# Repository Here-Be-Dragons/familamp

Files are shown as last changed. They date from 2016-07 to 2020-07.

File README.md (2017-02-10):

# familamp

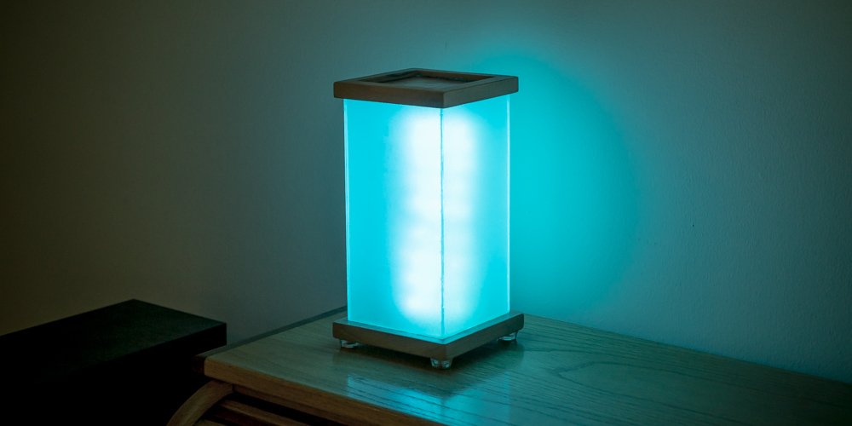
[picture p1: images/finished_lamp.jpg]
Finished Lamp Example


### Overview
---------------------
Networked lamps using a Particle Photon, WB2812B LEDs (aka NeoPixels), and a touch-sensitive panel.  They communicate and synchronize colors across lamps via the internet and Particle's cloud using Particle.subscribe() and Particle.publish() functions.  Bonus of using Particle's cloud: easily push updates and add features from Particle's browser-based IDE and Console.

### Images
---------------------
Demo of operation:  
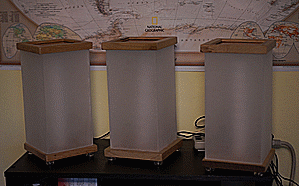
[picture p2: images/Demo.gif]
Demo Operation
  
https://youtu.be/uUX5NEsEXrw
  
Special mode idle sequences (instead of being off, the lamp runs an assigned idle sequence on holidays)
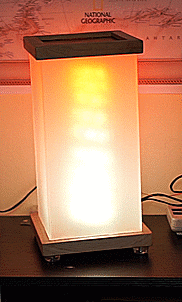
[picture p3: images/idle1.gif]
Christmas Idle

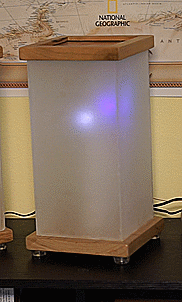
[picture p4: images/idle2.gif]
New Years/4th of July

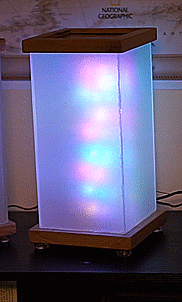
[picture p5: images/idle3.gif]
Birthdays

  
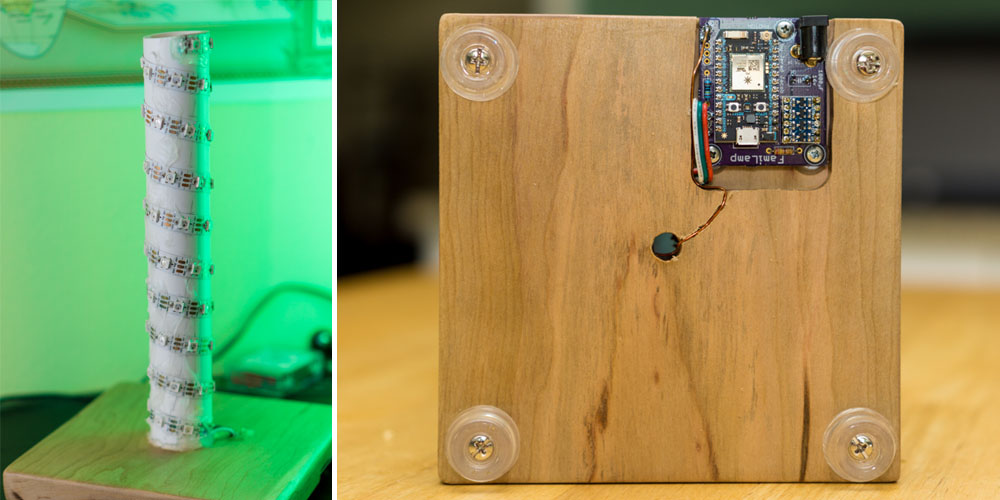
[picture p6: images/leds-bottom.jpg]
Bottom of lamp

  
Circuit boards from Osh Park:
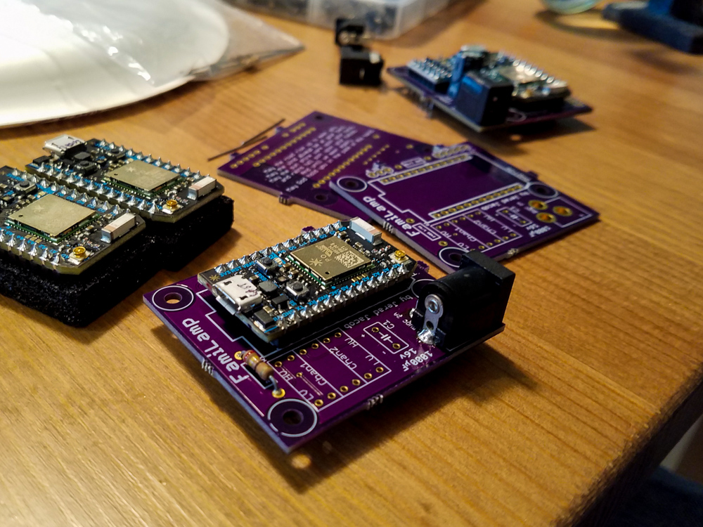
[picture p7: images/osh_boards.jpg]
Osh Park boards


### Hardware
---------------------
-   Particle Photon
-   WB2812B strip of LEDs.  I used 60 per lamp, because this seemed like a good match for my 2A power supplies.
-   A 3.3V to 5V logic level shifter to convert the 3.3V data bus from the Particle Photon to 5V the NeoPixels require.
-   Pre-cut acrylic pieces to make the acrylic light box.  TAP Plastics was the vendor I chose for this. (See *Other Note #1*)  For each lamp:
    -   2 cut-to-size 1/8" thick pieces, 5" x 9-7/8"
	-   2 cut-to-size 1/8" thick pieces, 4-3/4" x 9-7/8"
	-   1 cut-to-size 1/8" thick piece, 5" x 5"
-   A sheet of thin copper for the top.  I used a smooth ball peen hammer on the copper before installation to give it a hammered look.
-   Wood for the base and any flourishes you want for your lamps
-   3/4" x 3/4" outside corner moulding (if desired, to hide seems).
    -   http://www.homedepot.com/p/Alexandria-Moulding-WM-206-3-4-in-x-3-4-in-x-96-in-Wood-Red-Oak-Outside-Corner-Moulding-0W206-40096C/205917014
-   Custom PCB (I designed this in EAGLE and requested manufacture by OSH Park)
-   Other supporting bits (per lamp):
	-   1 resistor of value between 300 and 500 Ohms
	-   1 resistor of value between 1MOhm and 10MOhm (See *Other Note #2*)
	-   A barrel jack of matching dimensions to your power supply (Mine were 5.5mm with a 2.1mm center pole)
	-   A 5V power supply able to power the lamp.  I chose a UL listed supply of 2A. (See *Other Note #3*)
	-   Feet for the bottom of the lamp.  I grabbed some rubber feet from my local hardware supply store.
	-   Mounting hardware to attach the PCB.  I used small screws and standoffs from my local hardware supply store.

### Software
---------------------
-   Particle's Cloud
-   NeoPixel Library: https://github.com/adafruit/Adafruit_NeoPixel (Already ported to Particle's Libraries)
-   CapSense library: https://github.com/lbt/captouch (Already ported to Particle's Libraries)

### Assembly
---------------------
-   1MOhm resistor between pins D3 and D4 of the Particle Photon
-   D2 goes to a 3.3V to 5V Logic Level Shifter, then to a resistor of value between 300 to 500 Ohms, then to the data input pin of the NeoPixels.
    -   The resistor prevents voltage spikes that might otherwise damange the first pixel in the string.
-   D3 of the Particle Photon is connected to the touch sensitive hammered copper panel on the top of the lamp.
-   Connect a capacitor (1000µF, 6.3V or higher) across VIN and GND on the Particle Photon, then connect VIN and GND to the corresponding NeoPixel pins.
    -   The 1000µF capacitor prevents the initial onrush of current from damaging the pixels over time.  I ended up using a 500µF capacitor instead so it would fit my design's physical contraints better.
-   I used a 9" length of 1" PVC pipe to wrap the NeoPixels around, and hot-glued this into a hole in the top of the wood base.
    -   Do not use hot glue to glue the NeoPixels to the PVC pipe.  Either buy the NeoPixels with 3M tape on the back or use something like silicone (do not power the pixels on until after the time indicated for complete dry time on the glue of choice to prevent shorting the pixels).  When I used hot glue, this caused the strip to stop working correctly

### Other Notes & Lessons Learned
---------------------
1.  I tried saving money here by buying a large sheet of clear acrylic and cutting it myself, then sanding to make clear into frosted.  It turns out cutting acrylic is not easy to do well.  Abandoned this idea and bought clear acrylic pre-cut from a vendor, then sanded with 60-grit using a random orbital sander to frost the acrylic.  This still took forever.  If I were to do it again, I'd just buy pre-frosted with a medium light pass-through level.
2.  A lower resistance is less sensitive, but also polls faster. A high resistance takes longer to poll but can detect changes to capacitance with more sensitivity.  Prototype between 1MOhm and 10MOhm to see what works with your design.  I chose 1m ohm because the code loops back through a the captouch poll function frequently in the middle of effect transitions. It does this to try to be responsive to touch as quickly as possible.  In really dry weather it does slow down polling significantly which has the end result of making slightly stuttery animation effects, even with 1MOhm.
3.  Try to avoid power supplies that are not UL-Listed.  2A was a good middle ground for a reliable supply.  This device draws ~1A at 5V on its brightest setting during typical usage.  If all LEDs are at maximum brightness white (not something available in the current code), the lamp draws almost 3A.

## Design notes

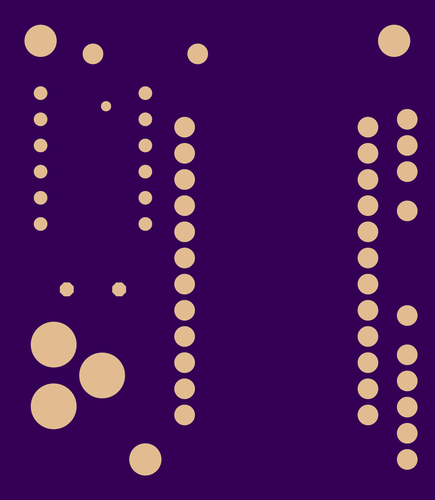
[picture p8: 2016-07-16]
images/OSH Park/ccddc78fc4526e5253ced44dfe0e408c.png

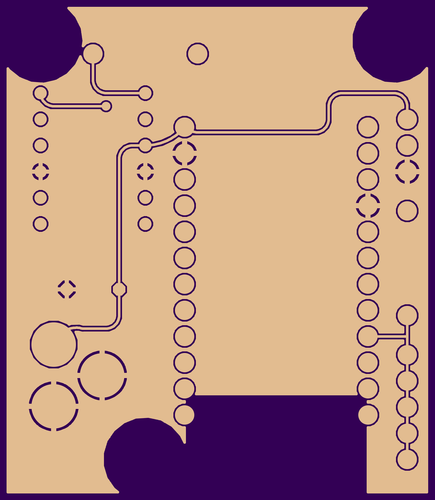
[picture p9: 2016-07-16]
images/OSH Park/2b33153ba39a5f5864be22afad9369f5.png

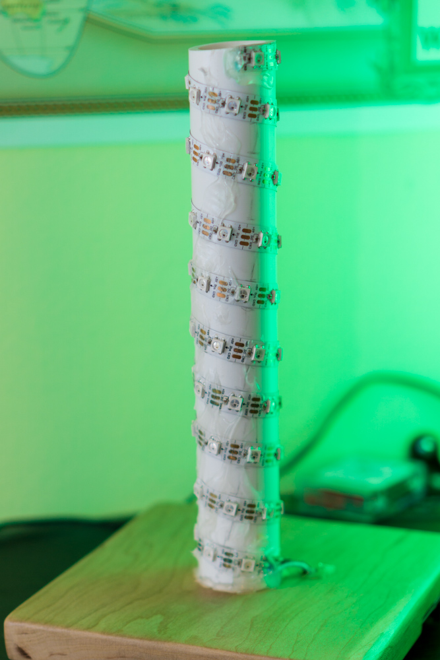
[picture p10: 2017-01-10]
images/leds.jpg

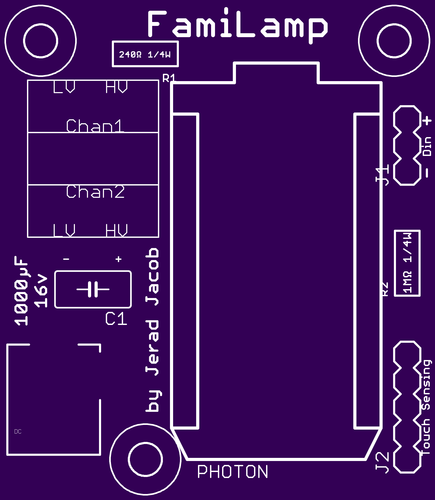
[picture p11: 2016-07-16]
images/OSH Park/a5ede5240e57ebc49895208856950a84.png

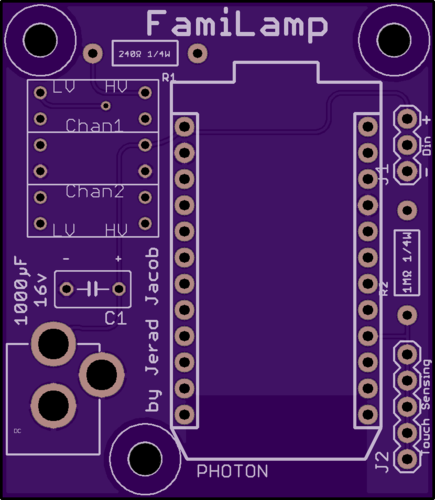
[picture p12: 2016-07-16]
images/OSH Park/2d7f82fe96bacb948cefc18041535cae.png

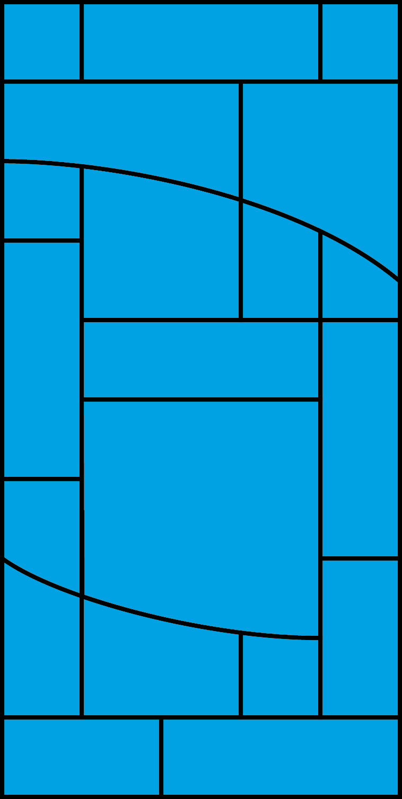
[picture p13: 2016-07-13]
images/SketchUp/familamp.png

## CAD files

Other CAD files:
images/SketchUp/familamp.skp

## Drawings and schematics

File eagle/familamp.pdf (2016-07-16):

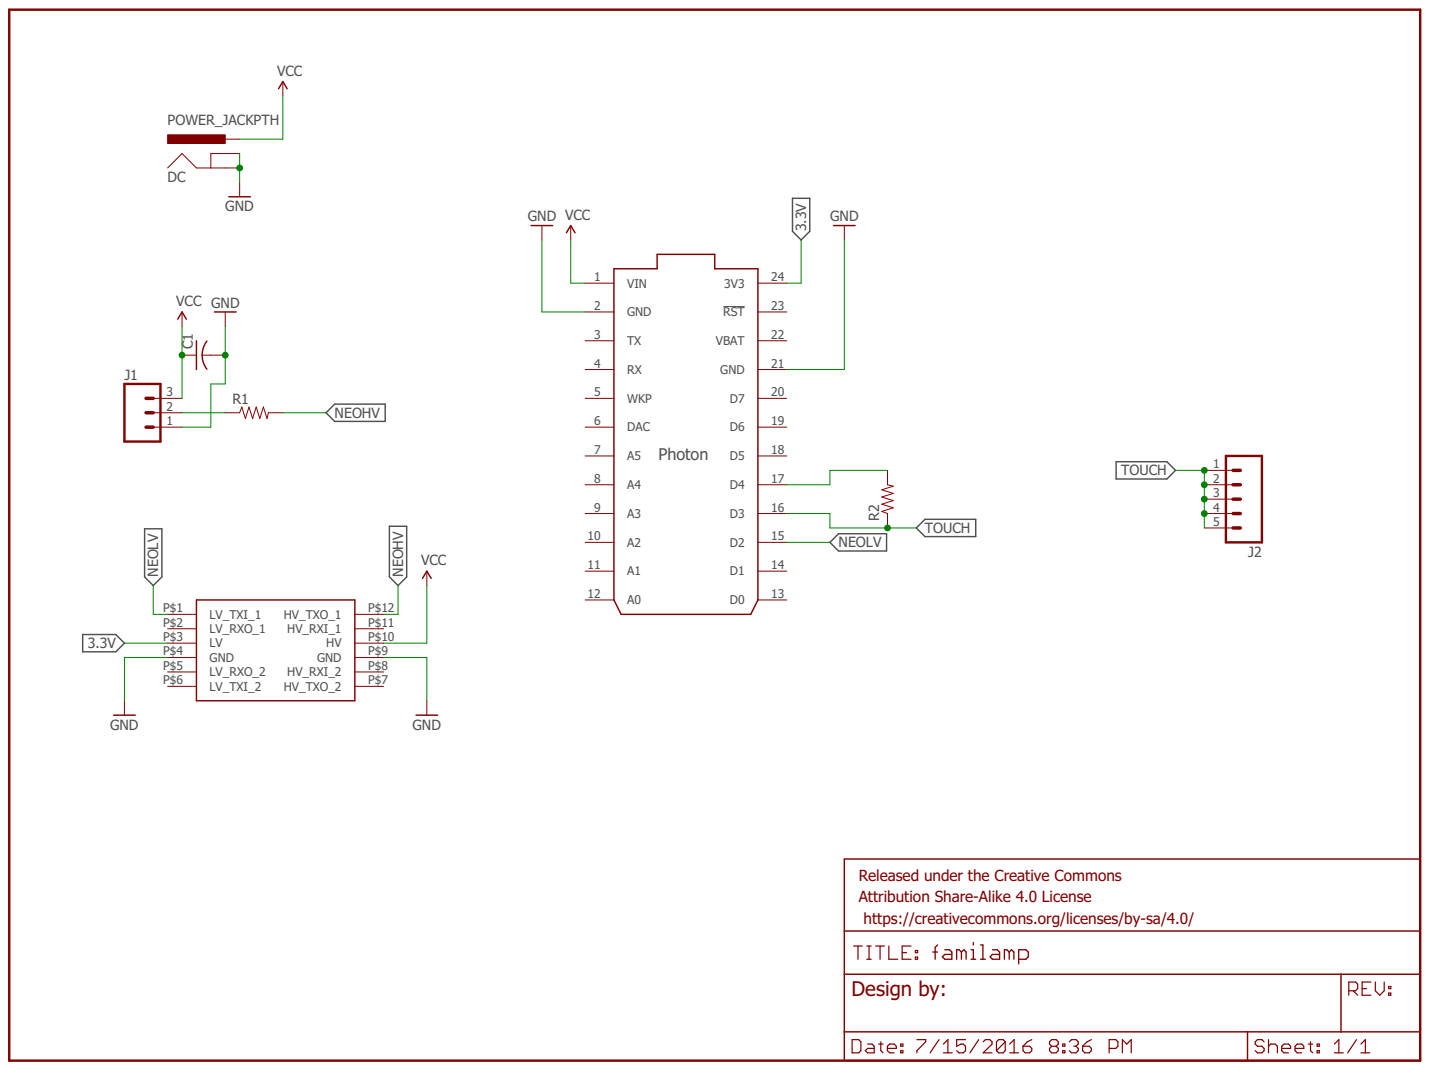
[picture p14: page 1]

Released under the Creative Commons Attribution Share-Alike 4.0 License https://creativecommons.org/licenses/by-sa/4.0/

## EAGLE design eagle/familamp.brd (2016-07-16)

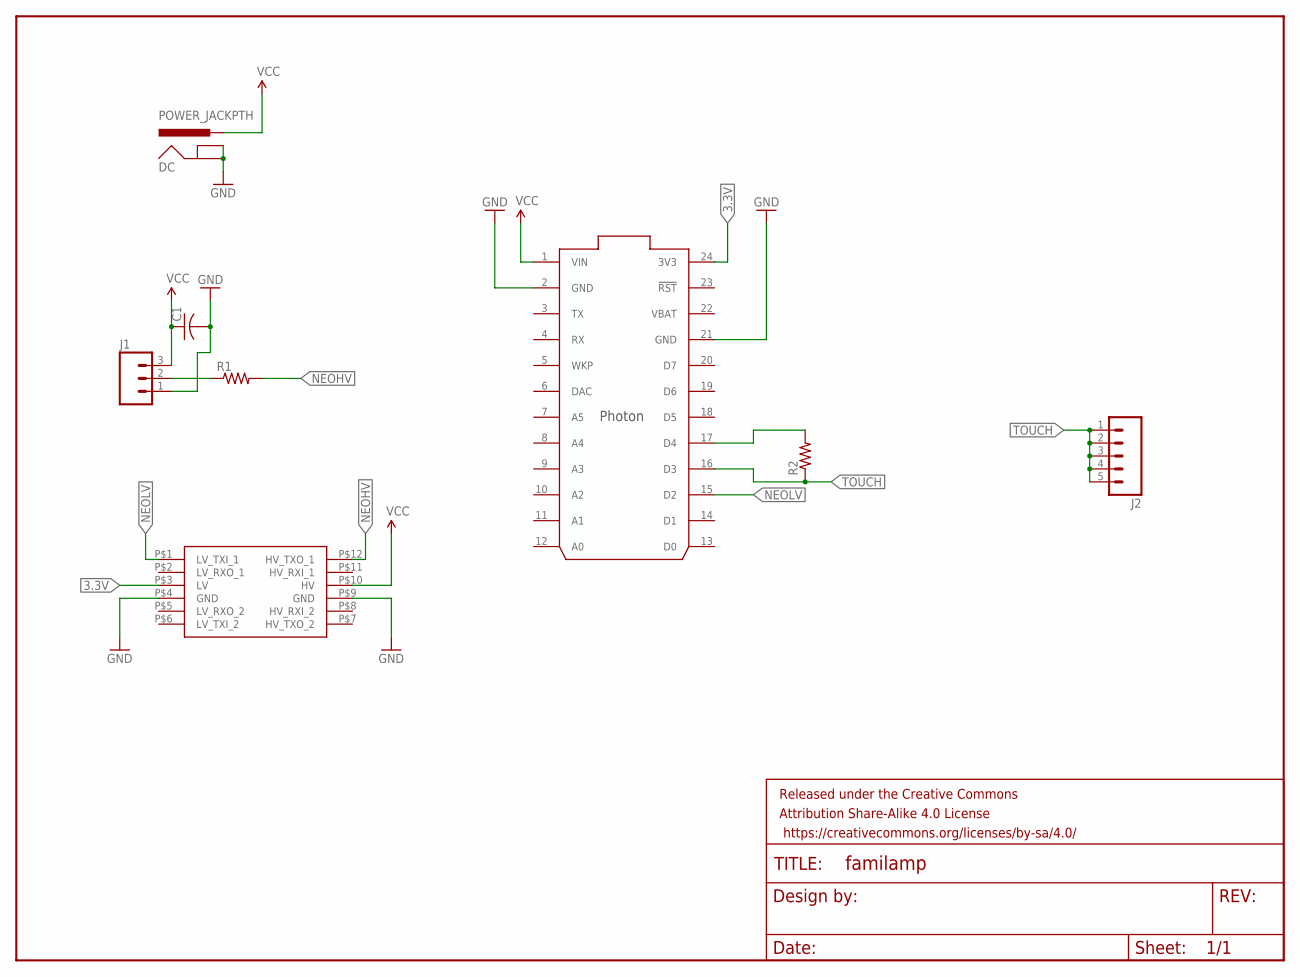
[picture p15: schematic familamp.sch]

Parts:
C1: C-US050-035X075; C050-035X075
DC: POWER_JACKPTH; POWER_JACK_PTH
FRAME1: FRAME-LETTER; CREATIVE_COMMONS
J1: M03PTH; 1X03
J2: M05PTH; 1X05
PHOTON: PHOTON_WITH_HEADERS; PHOTON
R1, R2: RESISTORPTH-1/4W; AXIAL-0.4
U$2: LOGIC_LEVEL_CONVERTER

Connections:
3.3V: PHOTON.24 (3V3), U$2.P$3 (LV)
GND: C1.2, DC.GND, DC.GNDBREAK, J1.1, PHOTON.2 (GND), PHOTON.21 (GND), U$2.P$4 (GND), U$2.P$9 (GND)
unnamed: J1.2, R1.P$1 (1)
unnamed: PHOTON.17 (D4), R2.P$2 (2)
NEOHV: R1.P$2 (2), U$2.P$12 (HV_TXO_1)
NEOLV: PHOTON.15 (D2), U$2.P$1 (LV_TXI_1)
TOUCH: J2.1, J2.2, J2.3, J2.4, J2.5, PHOTON.16 (D3), R2.P$1 (1)
VBAT: PHOTON.22 (VBAT)
VCC: C1.1, DC.PWR, J1.3, PHOTON.1 (VIN), U$2.P$10 (HV)

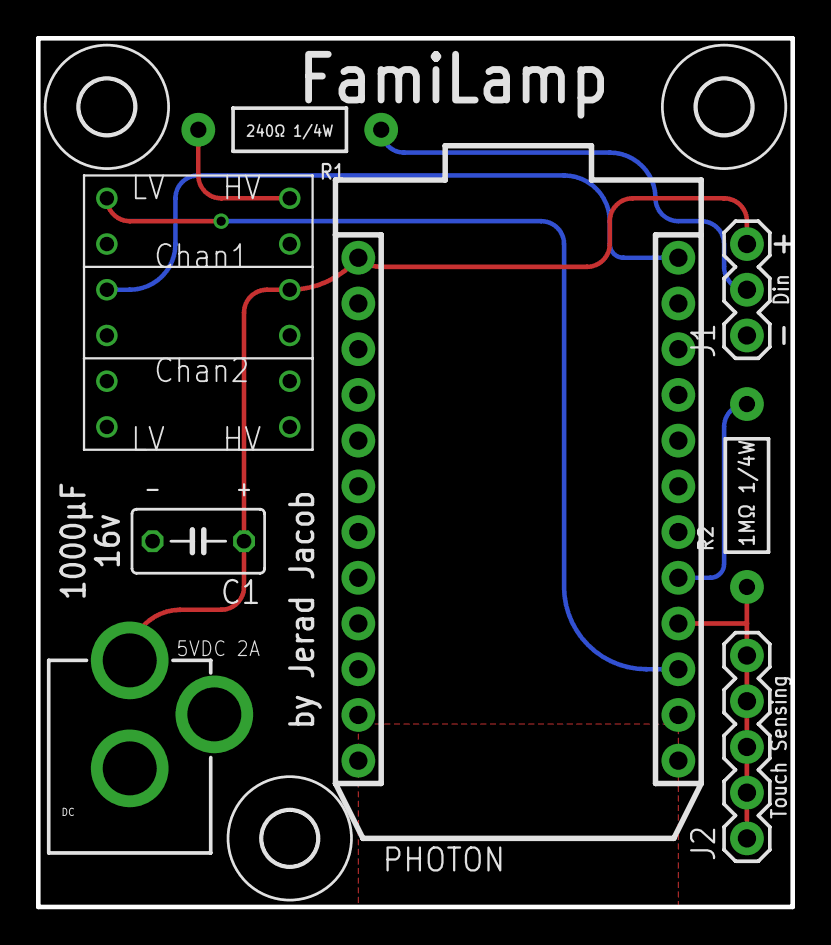
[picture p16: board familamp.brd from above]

Board: 2 copper layers, 41.9 x 48.3 mm, 12 parts (0 on the bottom side), 8 nets.

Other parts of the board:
U$3, U$4, U$5: 3,0

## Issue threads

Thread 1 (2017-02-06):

Directions

outrunthewolf, 2017-02-06:
For those who only have some experience with hardware, is this project do-able with off the shelf components? And if not, what would you advise?

This is great by the way. Do you have plans to build them as purchasable units?

Here-Be-Dragons, 2017-02-06:
I do not have plans to make purchasable units, but there are a couple other similar projects for sale around the internet.  The most time intensive part is the fabrication of the light box and top.  The electronics bit can be done with off-the-shelf components, and if you did not want to order PCBs they could be done with perfboard.  I find perfboard difficult to use, which is why I went the PCB route.

Closed 2017-04-11.

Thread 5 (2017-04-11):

How do you deal with double insulation?

KowalskiThomas, 2017-04-11:
Hey!
I'm kind of trying to do something similar to what you did, though I'm dealing with a problem I don't really know how to solve... And I think you should have met it too.
I purchased a power supply to... power my lamp you know, though it's double insulated, so as long as I use my capacitive sensor while plugged to my computer, everything goes right, but as soon as I unplug the microcontroller from the computer, the common ground is lost, hence the capacitive sensor doesn't work (since my ground is not the same as the controller's one). Have you dealt with that and, if so, how?
Thank you :)

Here-Be-Dragons, 2017-04-11:
Best I can tell all 5VDC power supplies are double insulated.  I do know that a high-quality supply is recommended by the various capacitive sensing articles I've read, to reduce noise and get a more accurate reading from the sensor, but I've had luck even from low-quality adapters.  UL-listed adapters seem to be a good idea to look for.  However, I don't believe a common ground is necessary, as I seem to recall I was able to successfully run the lamp from a portable battery pack (though I may be incorrect, I'll have to test this later and report back.)  If you're using the Particle Photon like I did, you can try using a high-quality Smartphone plug.  If it doesn't have the output rating you need, just adjust the sketch to use fewer LEDs.

If none of that is helpful, mind posting a schematic of your design?

KowalskiThomas, 2017-04-11:
I'm not using a Particle Photon (for various reasons, the first one being the price that was simply out of my means) but a NodeMCU.

I've tried to make the sensor work with various adapters (a Samsung one, an Apple one, my OnePlus 4A adapter, and finally a random Chinese one I had on my hands) and none of them allowed the capacitive sensor to work while not connected to the computer. Though, as expected, as soon as I draw a wire from the ground to something as a home appliance, the capacitive sensor works correctly...

I'll send a schematic, but since I'm not home right now it will wait a bit.

Here-Be-Dragons, 2017-04-12:
Confirmed that the touch does not work on a USB battery pack, so a ground is needed.  My implementation works using pretty much any AC->DC wall wart, though, so it is getting a grounded connection through the Neutral wire in the wall.

Here-Be-Dragons, 2017-04-17:
@KowalskiThomas Another user on the Particle Forums was having a similar issue and it appears to have been an incompatible resistor value for the sensing circuit.  Moving from 10MOhm to 1MOhm resolved their particular issue.  Can you play with increasing and decreasing the resistor on the touch circuit and see if it helps?

Related post: https://community.particle.io/t/familamp-cloud-synchronized-color-selectable-lamps/28589/30

KowalskiThomas, 2017-05-15:
Well, I randomly added a 100 pF (in series with the 1 MOhm resistor I already had) and now it's working. Can't explain it but as long as it works, it's none of my business.

Here-Be-Dragons, 2017-05-15:
Glad to hear.  If you end up with a finished product I'd love to see what you've made.  I'm closing this issue.

Closed 2017-05-15.

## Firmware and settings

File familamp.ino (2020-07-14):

#include "application.h"
#include "captouch.h"
#include <neopixel.h>

SYSTEM_MODE(AUTOMATIC);

CapTouch Touch(D3, D4);

#define PIXEL_COUNT 60
#define PIXEL_PIN D2
#define PIXEL_TYPE WS2812

Adafruit_NeoPixel strip = Adafruit_NeoPixel(PIXEL_COUNT, PIXEL_PIN);//, PIXEL_TYPE);

////
// User Variables
////

uint32_t decayTime = 2835;                  // Start extinguishing light after elapsed seconds
uint32_t decayDelay = 15;                    // Seconds between decay fade-out steps
uint8_t nightHours[2] = {6,      21};       // Night mode starts at nightHours[1], ends at nightHours[0]
uint8_t duskHours[2] =  {  7,  19  };       // Dusk mode starts at duskHours[1], ends at duskHours[0].  Needs to be inside nightHours' times.
                                            // Day mode starts at duskHours[0], ends at duskHours[1]
uint16_t maxDayBrightness = 180;            // 0 - 255, lamp will not exceed this during the day
uint16_t maxDuskBrightness = 40;            // 0 - 255, lamp will not exceed this during dusk
uint16_t maxNightBrightness = 3;            // 0 - 255, lamp will not exceed this during the night
uint32_t easterEggRollActivation = 20;      // Activates rainbowEasterEggroll after this many consecutive color changes

////
// End User Variables
////

double lastColorUpdate = 0;                 // Epoch of last color update (local or remote)
String colorFromID;                         // String, Tracks who sent the color (for debug)
uint16_t colorRecieved;                     // 0 - 255, Tracks the color received from another lamp
bool lampOn = 0;                            // Tracks if the lamp is lit
uint8_t activeColor = 0;                    // 0 - 255, Tracks what color is currently active (start at red)
uint8_t activeR = 255;                      // 0 - 255, Red component of activeColor;
uint8_t activeG = 0;                        // 0 - 255, Green component of activeColor;
uint8_t activeB = 0;                        // 0 - 255, Blue component of activeColor;
double lastDecayDelay = 0;                  // Time Tracker for decayDelay
uint16_t lampBrightness = 0;                // 0 - 255, Tracks current lamp brightness
uint16_t maxBrightness = maxDayBrightness;  // Assigned the current max brightness
uint8_t dayTrack = 0;                       // Track day/dusk/night condition
byte activePixels = 0;                      // Tracks number of active pixels, 0 is first pixel
byte pixelsForPicker = 0;                   // Counter during whileTouching()
uint8_t lastDay = 0;                        // Used to track if onceADay() has run yet today
uint8_t lastHour = 0;                       // Used to track if onceAnHour() has run yet this hour
double touchSenseHeartbeat = 0;             // Epoch of last touch heartbeat
double touchSenseHeartbeatRec = 0;          // Epoch of last touch heartbeat received
uint8_t sparklePixel = 0;                   // Track last pixel touched for sparkle effect

// Variables for special effects
uint32_t consecutiveChanges = 0;            // Track how many times the color has been changed before turning off
uint8_t fadeColor = 0;                      // Track color for special events
uint8_t fadePixelTracker = 0;               // Track last touched pixel for some idle sequences
float redStates[PIXEL_COUNT];               // Fireworks Variable
float blueStates[PIXEL_COUNT];              // Fireworks Variable
float greenStates[PIXEL_COUNT];             // Fireworks Variable
float fadeRate = 0.95;                      // Fireworks Variable: 0.01-0.99, controls decay speed
uint8_t heartbeatDirector = 0;              // Heartbeat Tracking
uint8_t heartbeatColor = 0;                 // Heartbeat Tracking
uint8_t easterEggrollColor = 0;             // Track color for rainbowEasterEggroll()
uint8_t easterMonth;                        // Stores this year's easter month.
uint8_t easterDay;                          // Stores this year's easter day.
CapTouch::Event touchEvent;

void setup() {
    strip.begin();
    strip.show();
    rainbowFull(5, 0); // 5ms Delay, 0 is fade in
    rainbowFull(5, 2); // 5ms Delay, 2 is fade out
    
    Touch.setup();
    
    Time.zone(-5);
    Time.setDSTOffset(1);
    getEasterDate();
    Time.beginDST();
    //Listen for other lamps to send a particle.publish()
    Particle.subscribe("FamiLamp_Update", gotColorUpdate, MY_DEVICES);
    Particle.subscribe("FamiLamp_Sparkle", gotTouchHeartbeat, MY_DEVICES);
}

void loop() {
    // True once every hour
    if (lastHour != Time.hour()) {
        onceAnHour();
        lastHour = Time.hour();
    }
    // True once every day
    if (lastDay != Time.day()) {
        onceADay();
        lastDay = Time.day();
    }
    touchEvent = Touch.getEvent();

    if (touchEvent == CapTouch::TouchEvent) {
        whileTouching();
    }
    if (Time.now() - lastColorUpdate > decayTime && lampOn == 1) {
        if (Time.now() - lastDecayDelay >= decayDelay) {
            extinguish();
            lastDecayDelay = Time.now();
        }
    }
    if (Time.now() - touchSenseHeartbeatRec < 5 && touchSenseHeartbeatRec > lastColorUpdate ) {
        touchSparkle();
    } else if ( sparklePixel != strip.numPixels() + 1 ) {
        removeSparkle();
        sparklePixel = strip.numPixels() + 1;
    }

    // Special idle functions
    if (lampOn == 0) {
        // Christmas Day
        if (Time.day() == 25 && Time.month() == 12) {
            idleColorFader(0,85);
        }
        // St. Patricks Day
        if (Time.day() == 17 && Time.month() == 3) {
            idleColorFlicker(21);
        }
        // Halloween
        if (Time.day() == 31 && Time.month() == 10) {
            idleColorFlicker(64);
        }
        // Valentines Day
        if (Time.day() == 14 && Time.month() == 2) {
            idleColorFlicker(106);
        }
        // 4th of July, RWB fireworks
        if ( Time.day() == 4 && Time.month() == 7 ) {
            idleFireworks(2);
        }
        // New Years Day, white fireworks
        if ( Time.day() == 1 && Time.month() == 1 ) {
            idleFireworks(1);
        }
        // Birthdays
        if (
            (Time.day() == 22 && Time.month() == 2) ||
            (Time.day() == 24 && Time.month() == 2)
            ) {
            idleDisco();
        }
        // Easter, relies on onceADay() and getEasterDate()
        if ( Time.day() == easterDay && Time.month() == easterMonth ) {
            //idleDisco();
            idleEaster();
        }
        // Unassigned Heartbeat
        //if (Time.day() == 22 && Time.month() == 10) {
        //    idleHeartbeat();
        //}
        // Unassigned mulitcolored fireworks
        
        /*if ( Time.day() == 1 && Time.month() == 1 ) {
            idleFireworks(0);
        }*/
    }
    // Easter Egg 1
    if (lampOn == 1 && (Time.month() * Time.day()) % 256 == activeColor) {
        rainbowEasterEggroll(0);
    }
    // Easter Egg 2
    if (lampOn == 1 && consecutiveChanges != 0 && consecutiveChanges % easterEggRollActivation == 0) {
        rainbowEasterEggroll(1);
    }
}

void whileTouching() {
    byte previousBrightness = lampBrightness; // Store the previous brightness in case we need it later
    uint16_t pixelBrightness = lampBrightness; // Tracks the given pixel's brightness.  Needs to track > 255, so uint16_t
    uint8_t testColor = activeColor; // Start with the current color
    pixelsForPicker = 0;
    double touchLoopTime;
    while (touchEvent != CapTouch::ReleaseEvent) {
        touchLoopTime = Time.now();
        if (touchLoopTime - touchSenseHeartbeat > 3) {
            sendSparkle();
            touchSenseHeartbeat = Time.now();
        }
        for (byte i = 0; i <= pixelsForPicker; i++) {
            pixelBrightness = lampBrightness + i; //Fade to full brightness
            if (pixelBrightness > maxBrightness) pixelBrightness = maxBrightness; //catch overflow
            // "pixelsForPicker - i" reverses the direction
            strip.setPixelColor(pixelsForPicker - i, wheelColor(((i * 60 / strip.numPixels()) + testColor) & 255, pixelBrightness)); // "& 255" AKA bitwise and prevents overflow
        }
        strip.show();
        testColor++; //because testColor is uint8_t, automatically loops at 256
        if(pixelsForPicker < (strip.numPixels() - 1)) pixelsForPicker++; //Add 1 for next iteration, but prevent looping around
        if(lampBrightness < maxBrightness) lampBrightness++;
        touchEvent = Touch.getEvent();
        delay(2);
    }
    if (pixelsForPicker >= (strip.numPixels() - 10)) {
        lampOn = 1;
        activeColor = testColor;
        sendColorUpdate();
        lastColorUpdate = Time.now();
    } else {
        lampBrightness = previousBrightness;
        setColorDither(activeColor);
    }
}

void sendColorUpdate() {
    String sColor = String(activeColor);
    Particle.publish("FamiLamp_Update", System.deviceID() + "~" + sColor, 60, PRIVATE);
}

void gotColorUpdate(const char *name, const char *data) {
    String str = String(data);
    char strBuffer[40] = "";
    str.toCharArray(strBuffer, 40);
    colorFromID = strtok(strBuffer, "~");
    colorRecieved = atof(strtok(NULL, "~"));
    lampBrightness = maxBrightness;
    lampOn = 1;
    consecutiveChanges++;
    activePixels = strip.numPixels();
    setColorDither(colorRecieved);
    // DEBUG
    String sColorRecieved = String(colorRecieved);
    Particle.publish("Color_Recieved", System.deviceID() + "~" + sColorRecieved);
    // END DEBUG
    lastColorUpdate = Time.now();
}

void gotTouchHeartbeat(const char *name, const char *data) {
    String sparkleFromID = String(data);
    if (sparkleFromID == System.deviceID()) {
        return;
    } else {
        touchSenseHeartbeatRec = Time.now();
    }
}

void sendSparkle() {
    Particle.publish("FamiLamp_Sparkle", System.deviceID(), 60, PRIVATE);
}

void setColorFade(byte c, byte ) { // c is color.  This function does a smooth fade new color.  Deprecated for new setColorDither()
    if (((Time.month() * Time.day()) % 256) == c) { // Semi-random formula to trigger easter egg
        rainbowEasterEgg();
    } else {
        uint8_t newR, newG, newB, startR, startG, startB, endR, endG, endB;
        uint32_t color = wheelColor(c, lampBrightness);
        endR = (uint8_t)((color >> 16) & 0xff); // Splits out new color into separate R, G, B
        endG = (uint8_t)((color >> 8) & 0xff);
        endB = (uint8_t)(color & 0xff);
        for (uint16_t fade = 0; fade < 255; fade++) {
            for (uint16_t j = 0; j < strip.numPixels(); j++) {
                long startRGB = strip.getPixelColor(j); // Get pixel's current color
                startR = (uint8_t)((startRGB >> 16) & 0xff); // Splits out current color into separate R, G, B
                startG = (uint8_t)((startRGB >> 8) & 0xff);
                startB = (uint8_t)(startRGB & 0xff);
                if (j > activePixels) {
                    newR = startR + (0 - startR) * fade / 255; // Color mixer to black
                    newG = startG + (0 - startG) * fade / 255;
                    newB = startB + (0 - startB) * fade / 255;
                } else {
                    newR = startR + (endR - startR) * fade / 255; // Color mixer
                    newG = startG + (endG - startG) * fade / 255;
                    newB = startB + (endB - startB) * fade / 255;
                }
                strip.setPixelColor(j, newR, newG, newB);
            }
            strip.show();
            delay(10);
        }
    }
    activeColor = c;
}

void setColorDither(byte c) { // c is color.  This function does a "random dither" to set the new color
    // April Fool's day: ignore the color you picked and replace it with something random
    if (Time.day() == 1 && Time.month() == 4) {
        c = random(0,255);
    }
    // Determine highest bit needed to represent pixel index
    uint32_t color = wheelColor(c, lampBrightness);
    int hiBit = 0;
    int n = strip.numPixels() - 1;
    for(int bit=1; bit < 0x8000; bit <<= 1) {
        if(n & bit) hiBit = bit;
    }
    
    int bit, reverse;
    for(int i=0; i<(hiBit << 1); i++) {
        // Reverse the bits in i to create ordered dither:
        reverse = 0;
        for(bit=1; bit <= hiBit; bit <<= 1) {
            reverse <<= 1;
            if(i & bit) reverse |= 1;
        }
        if ( ((Time.month() * Time.day()) % 256) == c) {
            easterEggrollColor = 0;
            color = wheelColor((reverse * 256 / strip.numPixels()) & 255, lampBrightness);
        } else if (consecutiveChanges != 0 && consecutiveChanges % easterEggRollActivation == 0) {
            easterEggrollColor = 0;
            color = wheelColor((reverse * 256 / 6) & 255, lampBrightness);
        }
        if (reverse > activePixels) {
            strip.setPixelColor(reverse, 0, 0, 0);
        } else {
            strip.setPixelColor(reverse, color);
        }
        strip.show();
        delay(20);
    }
    activeColor = c;
}

void extinguishFade() { //Dims the lamp by one unit until lampBrightness is 0 and lampOn is 0
    lampBrightness--;
    if (((Time.month() * Time.day()) % 256) == activeColor) { // Semi-random formula to trigger easter egg
        rainbowEasterEgg();
    } else {
        uint32_t color = wheelColor(activeColor, lampBrightness);
        for (byte j = 0; j <= strip.numPixels(); j++) {
            strip.setPixelColor(j, color);
        }
        strip.show();
        if (lampBrightness <= 0) {
            lampOn = 0; //If the lamp is completely off, set lampOn to 0
            consecutiveChanges = 0; //Reset counter for RainbowEasterEggroll() activation
            lampBrightness = 0; // Make sure this number isn't negative somehow
        }
    }
}

void extinguish() { //Turns off one pixel at a time until they're all off
    activePixels--;
    for(int i = 0; i <= strip.numPixels() - activePixels; i++) {
        strip.setPixelColor(strip.numPixels() - i, 0, 0, 0);
    }
    strip.show();
    if (activePixels <= 0) {
            lampOn = 0; //If the lamp is completely off, set lampOn to 0
            consecutiveChanges = 0; //Reset counter for RainbowEasterEggroll() activation
            lampBrightness = 0;
            activePixels = 0; // Make sure this number isn't negative somehow
        }
}

void extinguishOld() { //Dims the lamp by one unit until lampBrightness is 0 and lampOn is 0
    lampBrightness--;
    uint32_t color = wheelColor(activeColor, lampBrightness);
    for (byte j = 0; j <= strip.numPixels(); j++) {
        strip.setPixelColor(j, color);
    }
    strip.show();
    if (lampBrightness <= 0) {
        lampOn = 0; //If the lamp is completely off, set lampOn to 0
        consecutiveChanges = 0; //Reset counter for RainbowEasterEggroll() activation
        lampBrightness = 0; // Make sure this number isn't negative somehow
    }
}

uint32_t wheelColor(uint16_t WheelPos, uint16_t iBrightness) {
    float R, G, B;
    float brightness = iBrightness / 255.0;

    if (WheelPos < 85) {
        R = WheelPos * 3;
        G = 255 - WheelPos * 3;
        B = 0;
    } else if (WheelPos < 170) {
        WheelPos -= 85;
        R = 255 - WheelPos * 3;
        G = 0;
        B = WheelPos * 3;
    } else {
        WheelPos -= 170;
        R = 0;
        G = WheelPos * 3;
        B = 255 - WheelPos * 3;
    }
    activeR = R * brightness;// + .5;
    activeG = G * brightness;// + .5;
    activeB = B * brightness;// + .5;
    return strip.Color((byte) activeR,(byte) activeG,(byte) activeB);
}

void rainbowFull(byte wait, byte fade) {
  uint16_t i, j, k;
  uint16_t thisColor;
  if(fade == 0) k = 0;
  else k = maxBrightness;

  for(j = 0; j <= 255; j++) {
    for(i = 0; i < strip.numPixels(); i++) {
        thisColor = wheelColor(((i * 60 / strip.numPixels()) + j) & 255, k);
        strip.setPixelColor((strip.numPixels() - 1) - i, thisColor);
    }
    strip.show();
    delay(wait);
    if(fade == 0 && k < maxBrightness) {
        k++;
    }
    if(fade == 2 && k > 0) {
        k--;
    }
  }
}

void removeSparkle() {
    // Sparkle the lamp when another lamp is being touched
    if (lampOn == 1) {
        uint32_t color;
        if ( ((Time.month() * Time.day()) % 256) == activeColor) {
            color = wheelColor((sparklePixel * 256 / strip.numPixels()) & 255, lampBrightness);
        } else if (consecutiveChanges != 0 && consecutiveChanges % easterEggRollActivation == 0) {
            color = wheelColor((sparklePixel * 256 / 6) & 255, lampBrightness);
        } else {
            color = wheelColor(activeColor, lampBrightness);
        }
        strip.setPixelColor(sparklePixel, color);
    } else {
        strip.setPixelColor(sparklePixel, 0, 0, 0);
    }
    strip.show();
}

void touchSparkle() {
    removeSparkle();
    uint8_t sparkleBrightness;
    if (maxBrightness <= 250) {
        sparkleBrightness = maxBrightness + 5;
    } else {
        sparkleBrightness = maxBrightness;
    }
    sparklePixel = random(strip.numPixels());
    strip.setPixelColor(sparklePixel, sparkleBrightness, sparkleBrightness, sparkleBrightness);
    strip.show();
    delay(5);
}

void onceADay() {
    // Clear any previous day's special idles
    if (lampBrightness != 0 && lampOn == 0) {
        for (uint16_t i = 0; i < strip.numPixels(); i++) {
            strip.setPixelColor(i, 0, 0, 0);
        }
        strip.show();
        lampBrightness = 0;
    }
    getEasterDate();
}

void onceAnHour() {
    dayTracking();
}

void getEasterDate() {
    // Getting the date of easter is a giant pain.
    easterDay = (19 * (Time.year() % 19) + 24) % 30;        
    easterDay = 22 + easterDay + ((2 * (Time.year() % 4) + 4 * (Time.year() % 7) + 6 * easterDay + 5) % 7);
    // jump to next month
    if( easterDay > 31 ) {
        easterMonth = 4;
        easterDay -= 31;
    } else {
        easterMonth = 3;
    }
    // DEBUG
    String sEasterDay = String(easterDay);
    String sEasterMonth = String(easterMonth);
    String sTodayDay = String(Time.day());
    String sTodayMonth = String(Time.month());
    Particle.publish("This is Easter", "Month: " + sEasterMonth + ", Day: " + sEasterDay);
    Particle.publish("Today is", "Month: " + sTodayMonth + ", Day: " + sTodayDay);
    // END DEBUG
}

void rainbowEasterEgg() {
    // displays full rainbow, deprecated function now included in setColorDither() function
    for(uint8_t i = 0; i <= activePixels; i++) {
        strip.setPixelColor(i, wheelColor((i * 256 / strip.numPixels()) & 255, lampBrightness));
    }
    strip.show();
}

void rainbowEasterEggroll(byte type) {
    // displays full rainbow and rolls the color each time called
    uint16_t magicNumber;
    if (type == 1) {
        magicNumber = 6;
    } else if (type == 2) {
        magicNumber = 10;
    } else if (type == 3) {
        magicNumber = 12;
    } else {
        magicNumber = strip.numPixels();
    }
    for(uint8_t i = 0; i < activePixels; i++) {
        strip.setPixelColor(i, wheelColor(((i * 256 / magicNumber) + easterEggrollColor) & 255, lampBrightness));
    }
    strip.show();
    delay(10);
    easterEggrollColor++;
}

void dayTracking() {
    if (Time.hour() < nightHours[0] || Time.hour() >= nightHours[1]) { // Night hours
        if (dayTrack != 2) {
            maxBrightness = maxNightBrightness;
            if (lampBrightness > maxBrightness) lampBrightness = maxBrightness;
            setColorDither(activeColor);
            dayTrack = 2;
        }
    } else if (Time.hour() < duskHours[0] || Time.hour() >= duskHours[1]) { // Dusk hours
        if (dayTrack != 1) {
            maxBrightness = maxDuskBrightness;
            if (lampBrightness > maxBrightness) lampBrightness = maxBrightness;
            setColorDither(activeColor);
            dayTrack = 1;
        }
    } else { // Everything else is day
        if (dayTrack != 0) {
            maxBrightness = maxDayBrightness;
            if (lampBrightness > maxBrightness) lampBrightness = maxBrightness;
            setColorDither(activeColor);
            dayTrack = 0;
        }
    }
}

void idleColorFader(uint8_t c1, uint8_t c2) {
    // Slow fade between the two specified colors, `c1` and `c2`
    lampBrightness = 40;
    if ( maxBrightness < lampBrightness ) {
        lampBrightness = maxBrightness;
    }
    uint16_t currR, currG, currB, endR, endG, endB;
    uint32_t color = wheelColor(fadeColor, lampBrightness);
    endR = (uint16_t)((color >> 16) & 0xff); // Splits out new color into separate R, G, B
    endG = (uint16_t)((color >> 8) & 0xff);
    endB = (uint16_t)(color & 0xff);
    for (uint16_t j = 0; j < fadePixelTracker; j++) {
        long startRGB = strip.getPixelColor(j); // Get pixel's current color
        currR = (uint16_t)((startRGB >> 16) & 0xff); // Splits out current color into separate R, G, B
        currG = (uint16_t)((startRGB >> 8) & 0xff);
        currB = (uint16_t)(startRGB & 0xff);
        if ( currR > endR ) {
            currR = currR - 1;
        } else if ( currR < endR ) {
            currR = currR + 1;
        } else {
            currR = endR;
        }
        if ( currG > endG ) {
            currG = currG - 1;
        } else if ( currG < endG ) {
            currG = currG + 1;
        } else {
            currG = endG;
        }
        if ( currB > endB ) {
            currB = currB - 1;
        } else if ( currB < endB ) {
            currB = currB + 1;
        } else {
            currB = endB;
        }
        
        //Catch overflows
        currR %= 255;
        currG %= 255;
        currB %= 255;

        strip.setPixelColor(j, currR, currG, currB);
        if ( j >= strip.numPixels() - 1 && endR == currR && endG == currG && endB == currB) {
            if ( fadeColor == c1 ) {
                fadeColor = c2;
            } else {
                fadeColor = c1;
            }
            fadePixelTracker = 0;
        }
    }
    strip.show();
    if ( fadePixelTracker < strip.numPixels() ) fadePixelTracker++;
    delay(20);
}
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

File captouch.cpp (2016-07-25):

//============================================================
//	Touch Sensing Demo on Spark Core
//
//============================================================
//	Copyright (c) 2014 Tangibit Studios LLC.  All rights reserved.
//  Copyright (c) 2014 David Greaves <david@dgreaves.com>
//
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
//============================================================
#include "application.h"
#include "captouch.h"

// This has to be accessible by the ISR until the ISR supports lambdas
volatile unsigned long CapTouch_tR = 0;

CapTouch::CapTouch(int sensorPin, int driverPin) :
     m_intrIsAttached(false)
    ,m_pollTime(CAPTOUCH_POLL_TIME)
{
    m_driverPin = driverPin;
    m_sensorPin = sensorPin;
    m_touchSenseLast = LOW;
    m_touchDebounceTimeLast = 0;
    m_touchNow = LOW;
    m_touchLast = LOW;
	m_tLastDelay = 0;
}

void CapTouch::detachIntr() {
    detachInterrupt(m_sensorPin);
    m_intrIsAttached = false;
}

void CapTouch::attachIntr() {
    auto mylambda = [&]() {this->touchSense();} ;
    attachInterrupt(m_sensorPin, mylambda , RISING);
    m_intrIsAttached = true;
}

void CapTouch::setup()
{
    // intialize conditions for touch sensor
    pinMode(m_driverPin,OUTPUT);
    attachIntr();
    // calibrate touch sensor- Keep hands off!!!
    m_tBaseline = touchSampling();    // initialize to first reading
    m_tBaselineSum = m_tBaseline * CAPTOUCH_TOUCH_POOL;
	m_tJitterSum = 0;
	// time stamps
	m_lastUpdate = 0;
    
}

CapTouch::Event CapTouch::getEvent()
{
    CapTouch::Event touchEvent = CapTouch::NoEvent;
	//Update every POLL_TIME [ms]
	if (millis() > m_lastUpdate + m_pollTime)
	{
		// check Touch UI
		touchEvent = touchEventCheck();

		// time stamp updated
		m_lastUpdate = millis();
	}
	return(touchEvent);
}

//------------------------------------------------------------
// ISR for touch sensing
//------------------------------------------------------------
void CapTouch::touchSense()
{
    CapTouch_tR = micros();
}

//------------------------------------------------------------
// touch sampling
//
// sample touch sensor 32 times and get average RC delay [usec]
//------------------------------------------------------------
long CapTouch::touchSampling()
{
    long tDelay = 0;
    int mSample = 0;
	long jitter = 0;
    
    for (int i=0; i<32; i++)
    {
        // discharge capacitance at rPin
        pinMode(m_sensorPin, OUTPUT);
        digitalWrite(m_driverPin,LOW);
        digitalWrite(m_sensorPin,LOW);
		// Now give the pin time to actually go low and drain "the
		// capacitor"
        delay(2);
        // revert to high impedance input
        pinMode(m_sensorPin,INPUT);
        
        // timestamp & transition sPin to HIGH and wait for interrupt
        // in a read loop
        m_tS = micros();
        CapTouch_tR = m_tS;
        digitalWrite(m_driverPin,HIGH);
        do
        {
            // wait for transition - interrupt handler will set tR
        } while (digitalRead(m_sensorPin)==LOW);
        
        // accumulate the RC delay samples
        // ignore readings when micros() overflows
        if (CapTouch_tR>m_tS)
        {
            tDelay = tDelay + (CapTouch_tR - m_tS);
            mSample++;
        }
        
    }
	// Leave it in LOW mode keeping the capacitor drained.
	pinMode(m_sensorPin, OUTPUT);
	digitalWrite(m_sensorPin,LOW);
    
    // calculate average RC delay [usec]
    if (mSample>0)
    {
        tDelay = tDelay/mSample;
		m_tLastDelay = tDelay;
	}
    else
    {
        tDelay = 0;     // this is an error condition!
#ifdef CAPTOUCH_DEBUG
		Serial.println("Error - no delay obtained in sample");
#endif
	}

    // autocalibration using moving average of 1/5 of pool size
	// when in Releas-ed state.
	if (m_touchSenseLast == LOW) {
		m_tBaselineSum += (tDelay - m_tBaseline) * 2;
		m_tBaseline = m_tBaselineSum / CAPTOUCH_TOUCH_POOL;
		if (tDelay > m_tBaseline) {
			jitter = tDelay - m_tBaseline;
		} else {
			jitter = m_tBaseline - tDelay;
		}
		m_tJitterSum -= m_tJitter;
		m_tJitterSum += jitter;
		m_tJitter = m_tJitterSum / CAPTOUCH_JITTER_POOL;
	} else {
		// auto calibrate *really* slowly in Touch-ed state to allow
		// for a touch-pad to be connected after setup() has run;
		// disconnected/reconnected or other odd changes. Technically
		// this means that a Touch event will time out eventually.
		// In practice this is order of minutes.
		// tDelay is always > m_tBaseline in Touch
		m_tBaselineSum++;
		m_tBaseline = m_tBaselineSum / CAPTOUCH_TOUCH_POOL;
	}

    #ifdef CAPTOUCH_DEBUG
	Serial.print("check at ");
	Serial.print(m_lastUpdate);
	Serial.print(" Delay:baseline:jitter=");
	Serial.print(tDelay);
	Serial.print(":");
	Serial.print(m_tBaseline);
	Serial.print(":");
	Serial.print(m_tJitter);
	#endif

    return tDelay;
    
}

//------------------------------------------------------------
// touch event check
//
// check touch sensor for events:
//      NoEvent       no change
//      TouchEvent    sensor is touched (Low to High)
//      ReleaseEvent  sensor is released (High to Low)
//
//------------------------------------------------------------
CapTouch::Event CapTouch::touchEventCheck()
{
    unsigned long touchSense;                             // current reading
    unsigned long touchDebounceTime = 50;                 // debounce time
    CapTouch::Event tEvent = CapTouch::NoEvent; // default event
    
    // read touch sensor
    m_tReading = touchSampling();
    
    // touch sensor is HIGH if trigger point 1.25*Baseline
    if (m_tReading>(m_tBaseline + m_tBaseline/4) &&
		m_tReading>(m_tBaseline + m_tJitter*2)) {
		touchSense = HIGH;
	} else {
        touchSense = LOW; 
    }
    
    // debounce touch sensor
    // if state changed then reset debounce timer
    if (touchSense != m_touchSenseLast) {
        m_touchDebounceTimeLast = millis();
    }
    
    m_touchSenseLast = touchSense;
    
    // accept as a stable sensor reading if the debounce time is exceeded without reset
    if (millis() > m_touchDebounceTimeLast + touchDebounceTime) {
        m_touchNow = touchSense;
    }
    
    
    // set events based on transitions between readings
    if (!m_touchLast && m_touchNow) {
        tEvent = TouchEvent;
    }
    
    if (m_touchLast && !m_touchNow) {
        tEvent = ReleaseEvent;
    }
    
    // update last reading
    m_touchLast = m_touchNow;
    #ifdef CAPTOUCH_DEBUG
    Serial.print("  Event:");
    if (tEvent == TouchEvent)
        Serial.println(" Touch");
    else if (tEvent == ReleaseEvent)
        Serial.println(" Release");
    else if (tEvent == NoEvent)
        Serial.println(" None");
	#endif
	
    return tEvent;
}

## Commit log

2016-07-13 Created 3D render
    [familamp.skp]
2016-07-13 Added CapacitiveSensor library
2016-07-13 Added assembly instructions
2016-07-14 Added moulding link
2016-07-16 Finished board design
    [familamp.brd, familamp.sch]
2016-07-16 Board design previews
2016-07-16 Final Board Design (I HOPE)
    [familamp.brd]
2016-08-02 Fixed locking issue with extinguish()
    [familamp.ino]
2016-08-04 bug fix to extinguish()
    [familamp.ino]
2016-08-05 Down to 1 bug
    Colors smoothed and reversed to "well up" and "drain out" when touched.
    [familamp.ino]
2016-12-05 Fixed the update fader
    setColor() fades properly now.
    [familamp.ino]
2016-12-13 Added delayed extinguish function + fixed 1 bug
    Bug: Missing
    ```activeColor = color;
    in setColor(), so activeColor never getting set.
    [familamp.ino]
2016-12-28 Added New Years Special Idle
    NEW FEATURES:
    Fireworks idle sequence.
    BUGFIXES:
    activePixels not setting to 0 on each touch.
    [familamp.ino]
2016-12-28 Clear special idle sequence day after
    - Changed "New Years" to "Fireworks", also applies 4th of July
    - Lamp now dims between 8pm and 7am
    - Idle sequences clear (as needed) 12:00AM the following day.
    OTHER:
    - Moved user-defined settings to the top of the code
    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
    [familamp.ino]
2017-01-10 Bugfixes to release 9
    [familamp.ino]
2017-01-26 Changes and Updates to Release 12
    - New Heartbeat Idle Sequence (currently not assigned)
    - New New Idle Color Flicker Sequence (St. Patty's and Valentines)
    - Adjusted brightness of a few things here and there
    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
2017-02-09 Removed Extra Files
    [FamiLamp.sch]
2017-02-10 Changes and updates to Release 13
    - New setColor() does a dither instead of fade
    - Adjusted brightness of night mode
    - Idle sequences cannot be brighter than max brightness for a given time
    BUG FIXES:
    - Release 12 would not compile due to missing lines
    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
    [familamp.ino]
2017-03-07 Tweaks and new Easter Eggroll
    - After 30 triggers in a row without going dark, trigger Easter Eggroll!
    - Dither now works for Easter Eggs
    - Night mode now a brightness of 5, down from 20.
    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
    [familamp.ino]
2017-03-09 Added easter holiday + code streamlining
    - Added math to calculate easter for the current year for idleEaster().
    - Removed my product ID, as this is not useful for others.
    - Created a onceADay() and onceAnHour() function inside loop() to limit how often certain code runs.
    - Moved the many easter egg functions into one with a passed variable to shorten code.
    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
    [familamp.ino]
2017-03-18 Fix for #3
    Last pixel on lamp not updating properly due to `strip.numPixels() - 1`. Changed to `strip.numPixels()`
    [familamp.ino]
2017-04-10 Naming Cleanup
    [familamp.brd, familamp.sch]
2017-04-21 New extinguish
    - New pixel-by-pixel extinguish function
    - Added DST offset to each timezone
    - Applied DST permanently (will need to be changed for next DST change)
    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
    [familamp.ino]
2017-05-15 Fixed formatting from last commit
    [familamp.ino]

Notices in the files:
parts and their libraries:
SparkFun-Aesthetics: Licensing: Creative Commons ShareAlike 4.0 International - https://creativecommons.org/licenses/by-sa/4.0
